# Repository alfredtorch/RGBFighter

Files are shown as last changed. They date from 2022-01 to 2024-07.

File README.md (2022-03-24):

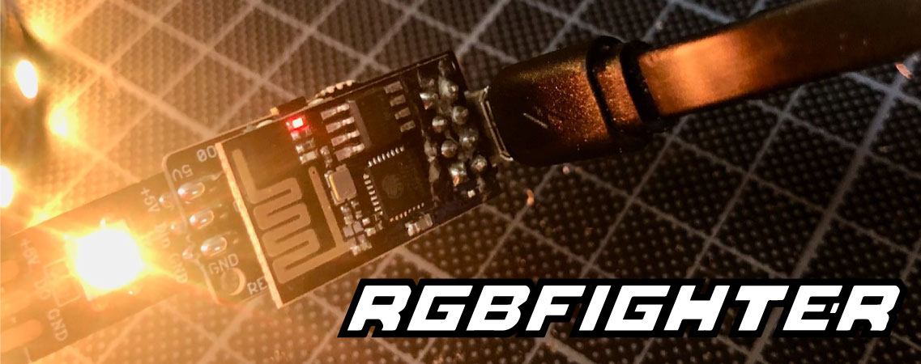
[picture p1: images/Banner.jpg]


🚥 Micro ESP-01 board for addressable pixel control 🚥 ... suits to every place and mostly to any needs!
Only a power bank and a smartphone are needed and you're good to go with your mobile setup.

* Small : +- 14x32mm & Lightweight : +- 4gr
* ESP8266 based (Support for Arduino)
* Designed for common LED Strips like WS2812 with level shifting
* Connection over 2,54 mm 3 Pin for direct soldering, JST or screw terminal (Version Strip or Panel)
* Power and Progamming over USB (CP2104 nodeMCU design)
* User Input for One Button OR IR Receiver
* [WLED](https://github.com/Aircoookie/WLED "WLED's Github page") compatible
* Inspirations from Adafruit, Sparkfun and many others

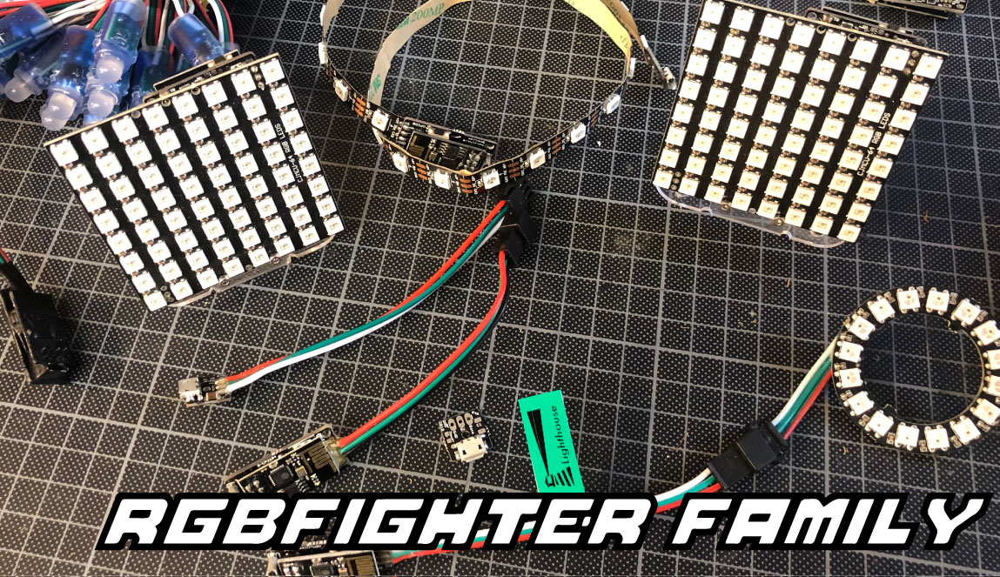
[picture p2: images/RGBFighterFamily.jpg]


# ⚡️PCB 
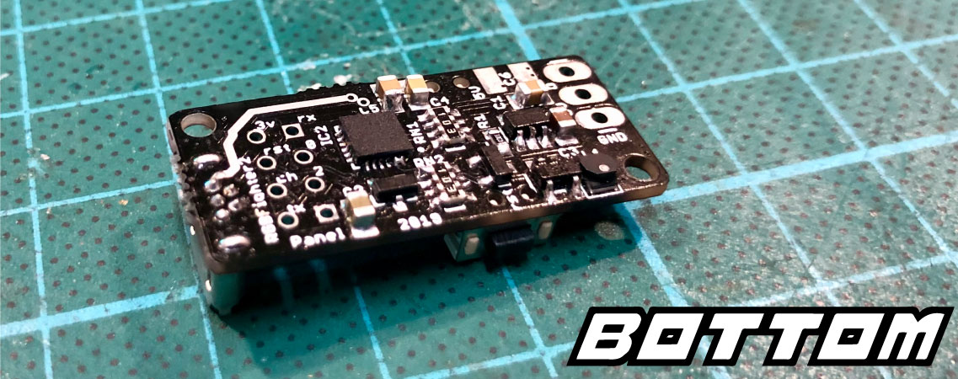
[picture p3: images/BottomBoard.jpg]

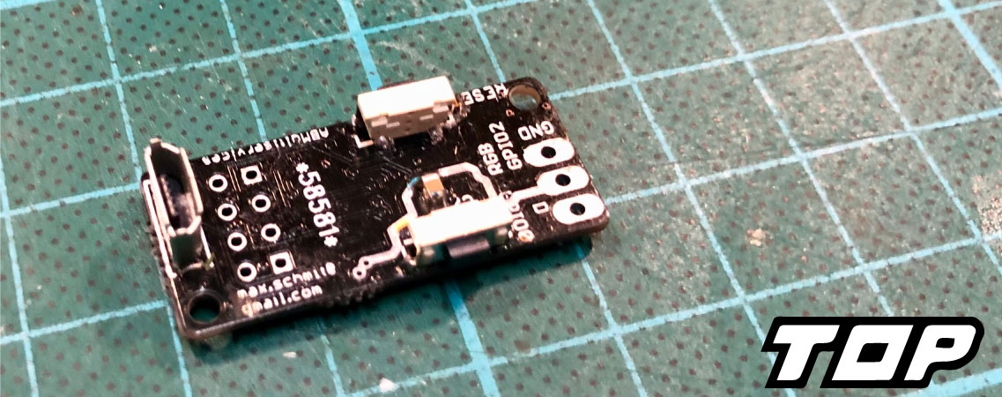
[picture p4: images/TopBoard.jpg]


# 🔦 Hardware

At the moment I have no possibility for a larger production and distribution. Of course, I am ready for any cooperation to industrialize the production. Happy to get any proposition.

## 🗺 Design Files

Designed in Eagle, in a messy way! Sorry! The related files are available under /Hardware.
Name | Description 
--- | ---
ButtonPanel | Panel and Button
ButtonStrip | Strip and Button
IR | Strip and IR Receiver
PowerRail | Power for 8 Strips
PowerDistributorX30 | 5 Ports XT-30 Connector

## 🛠 For DIY'er:
All you need are steady hands for the soldering part, specially the QFN. A reflow or hot plate is suggested.
The thickness of the board should be 1,2mm in order to sold the vertical USB firmly. The parts can be easily ordered from the common suppliers.

## 💰BOM

Part Name | Quantity | Price | Supply Link | Notes 
--- | --- | --- | --- | ---
Board RGBFighter | 1 | 0,02€ | [DirtyCheapPCB](https://dirtypcbs.com/store/pcbs/buy/108056/rgborder10x10january2019-zip) | Panelised Design files of Panel-Strip-USB Versions
ESP-01 MCU | 1x | 2€ | [Amazon](https://amzn.to/3qxXip7) | The brain with Wifi!
CP2104 USB Controller | 1x | 3€ | Mouser, ... | need for progamming : alternative [ESP-01 Flasher Amazon](https://amzn.to/3A2HptF) - [Aliexpress](https://s.click.aliexpress.com/e/_9JcISN)
Micro USB Vertical | 1x | 0,5€ | [Aliexpress](https://s.click.aliexpress.com/e/_AaeVzr)
Resistor Array 603 10k | 2x | 0,2€ | Mouser, ... | Pull-up registors for programming and normal operation
Transistor MMBT2222 | 2x | 0,2€ | Mouser, ... | need for programming, NPN Type
Capacitor 0805 | 3x | 0,2€ | Mouser, ... | Various values : schematics
Inducator 2.2uH | 1x | 0,2€ | Mouser, ... | NRH2412T2R2MNGH
3V3 Step Down Converter | 1x | 1,2€ | Mouser, ... | LM3671
Reistor 300Ohm 0805 | 1x | 0,2€ | Mouser, ... | basic pin protection 
Level Shifter SN74LVC1T45DBV  | 1x | 0,2€ | Mouser, ... | for the right Voltage on the Data bus
Button G71Y | 2x | 0,2€ | [Aliexpress](https://s.click.aliexpress.com/e/_A68Ds9) | MCU & Reset User Input
IR Receiver | 1x | 0,2€ | [Aliexpress](https://s.click.aliexpress.com/e/_A7jhiZ) |IR Control Version

🙏 Please if you need to shop for parts, it would be great that you use the supply links below. As they are affilated, you're supporting me directly to continue to deliver new projects to the community! Thank you ❤️
<p align="center">

</p>

# 🎆 Versions
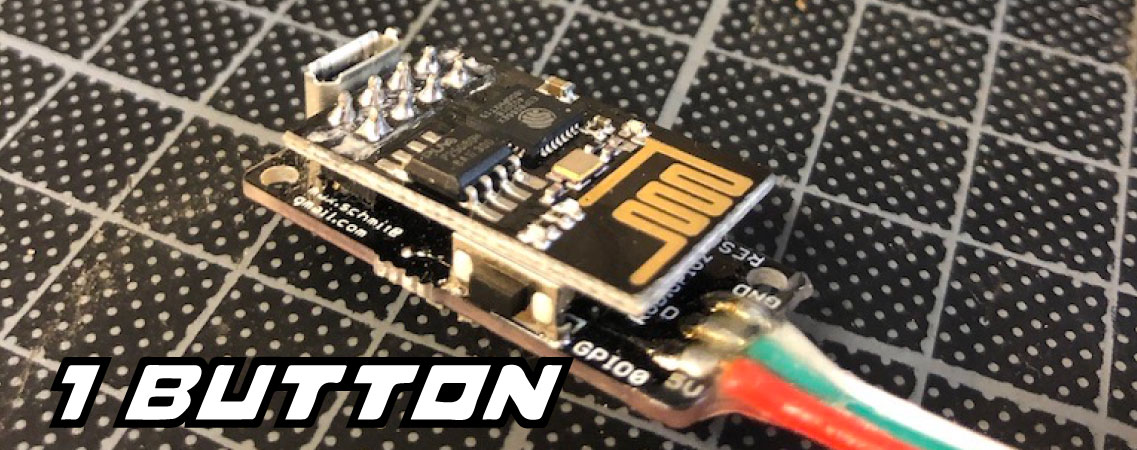
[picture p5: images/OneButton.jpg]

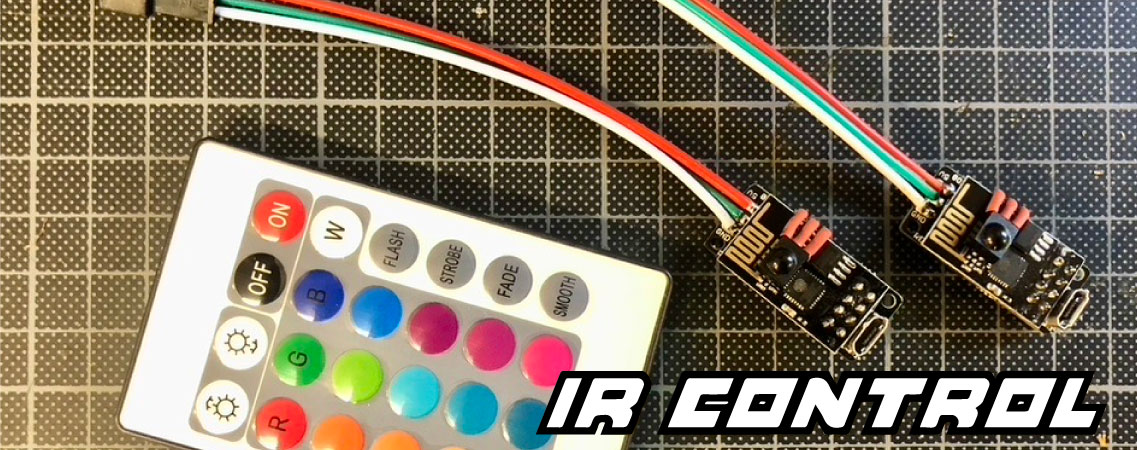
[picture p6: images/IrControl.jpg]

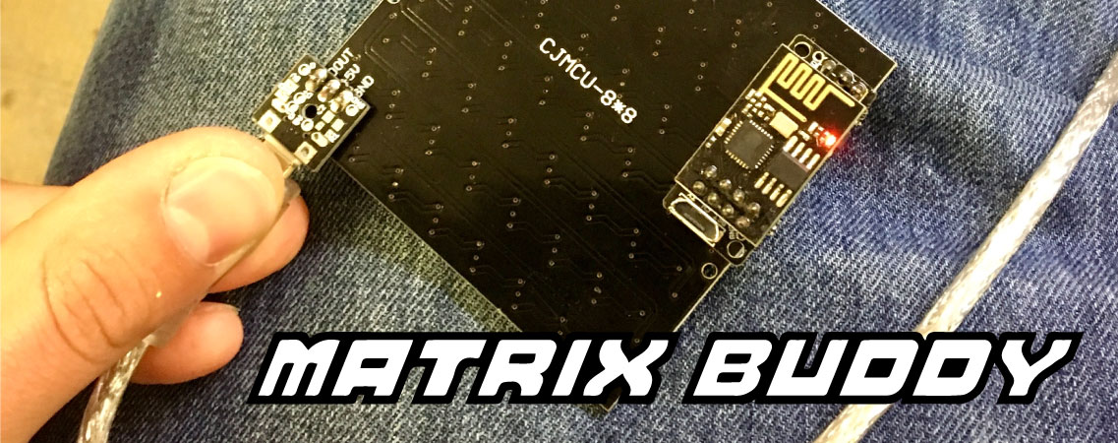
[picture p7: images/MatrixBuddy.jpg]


# 📖 History and Evaluation

It started longtime ago when I wanted an easy way to drive my pixels. First pcb version was sended to fabrication in july 2016. 
Since the project evolved into something more advanced and more mature!

## 🔍 Development Phase
ToDo | Remarks
--- | --- 
Easy Boards | Design boards without programming chip but with easy to solder buttons and voltage converter 
Documentation | Improve the transfer of knowledge
Big production | Looking forward to have some input, help to release it massivly, if wanted.

# 🛒 Accessories

Most of these parts can be laser cutted. The related files are available under Hardware/RGBFighterLaserParts.dxf

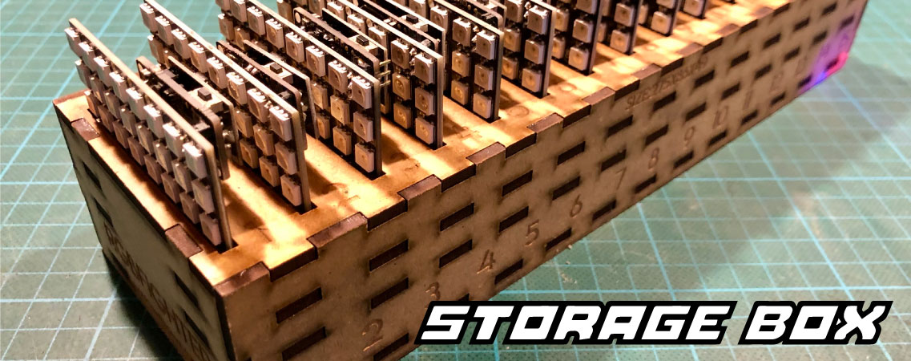
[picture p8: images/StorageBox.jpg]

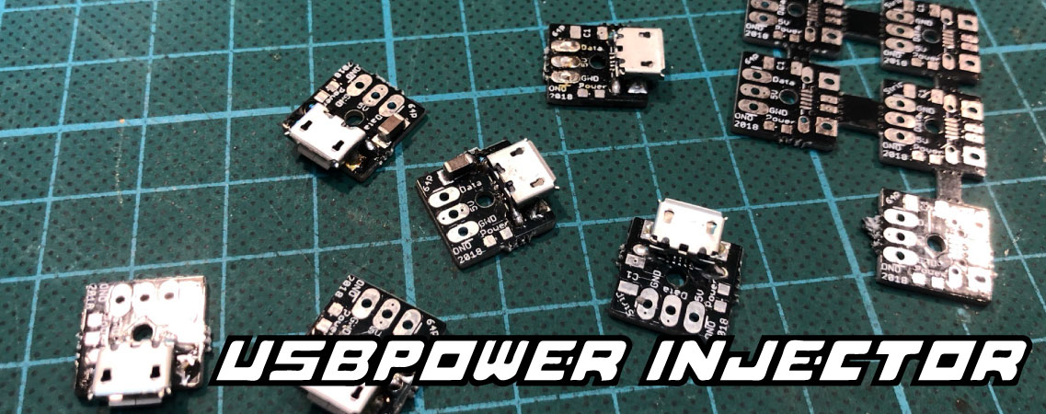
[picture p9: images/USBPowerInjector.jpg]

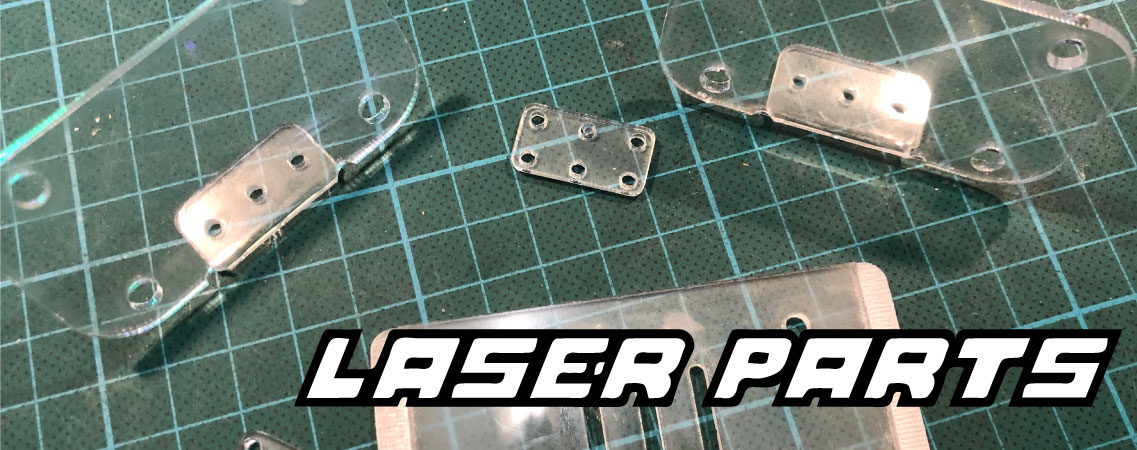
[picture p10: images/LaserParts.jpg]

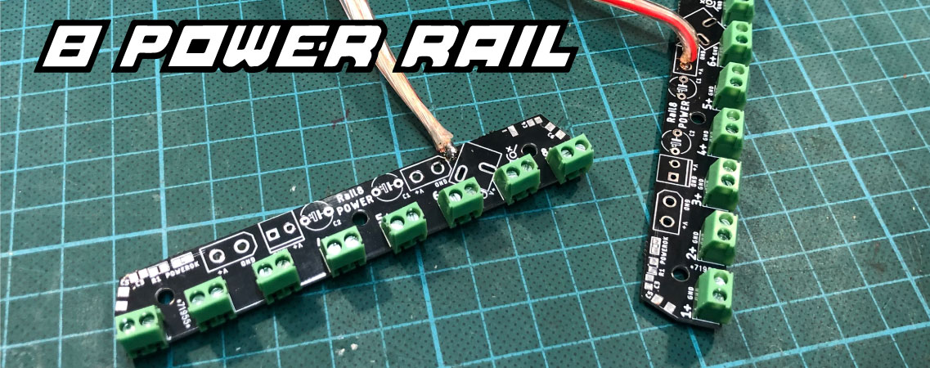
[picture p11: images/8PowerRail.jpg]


# 👶🏼 First Steps & Ideas

⚠️Don't mess with the power - no polarity or whatever protection ⚠️

⚠️Vertical USB is fragile - Handle with care ⚠️

## 🤏🏽 Pinout
Pin | Function
--- | ---
GPIO0 | Button Or InfraRed
GPIO2 | RGB Output | Recomanded Output from WLED

## 💾 Programming
You can directly check the [How-To from WLED](https://kno.wled.ge/basics/install-binary/)

## 🪛 Tutorials
see [Tutorials Page](https://github.com/alfredtorch/RGBFighter/blob/master/Tutorials.md)

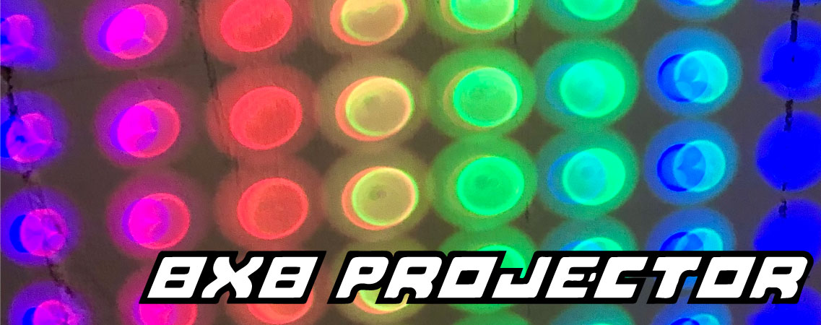
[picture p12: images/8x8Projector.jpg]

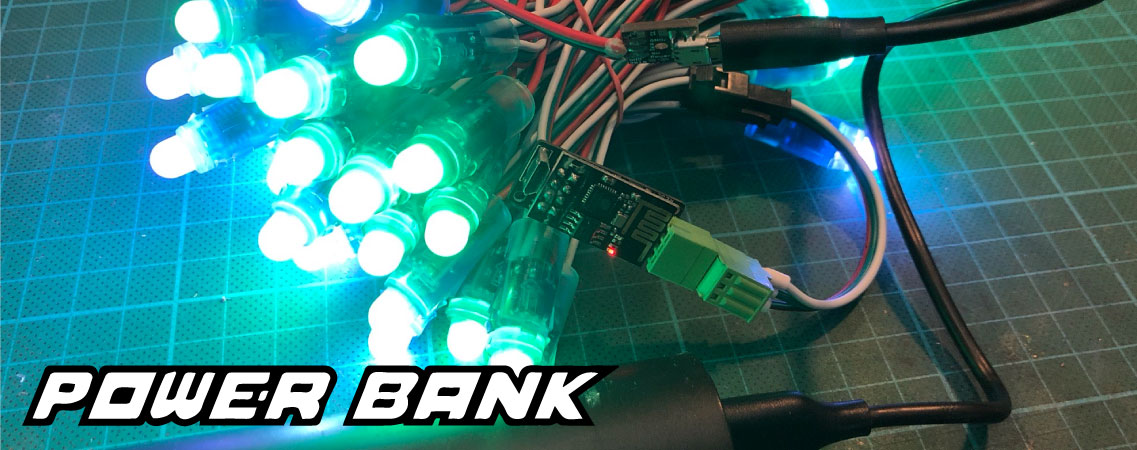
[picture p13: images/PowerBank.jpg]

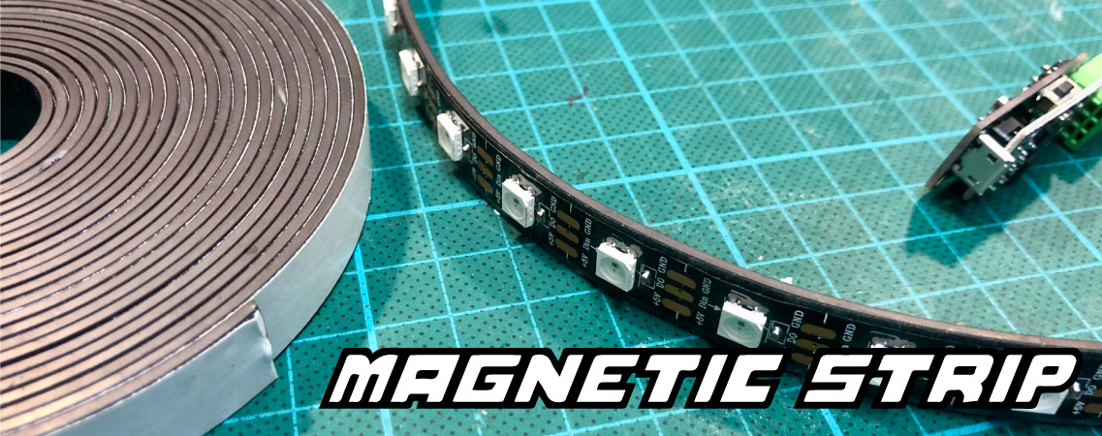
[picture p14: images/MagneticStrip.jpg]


Servo, Electro-Dipped, ...

---

# ⚖️ Licence
The MIT License (MIT)

Copyright (c) 2021 Max Schmit

Permission is hereby granted, free of charge, to any person obtaining a copy of this Hardware and associated documentation files (the "Hardware"), to deal in the Hardware without restriction, including without limitation the rights to use, copy, modify, merge, publish, distribute, sublicense, and/or sell copies of the Hardware, and to permit persons to whom the Hardware is furnished to do so, subject to the following conditions:

The above copyright notice and this permission notice shall be included in all copies or substantial portions of the Software.

THE HARDWARE IS PROVIDED "AS IS", WITHOUT WARRANTY OF ANY KIND, EXPRESS OR IMPLIED, INCLUDING BUT NOT LIMITED TO THE WARRANTIES OF MERCHANTABILITY, FITNESS FOR A PARTICULAR PURPOSE AND NONINFRINGEMENT. IN NO EVENT SHALL THE AUTHORS OR COPYRIGHT HOLDERS BE LIABLE FOR ANY CLAIM, DAMAGES OR OTHER LIABILITY, WHETHER IN AN ACTION OF CONTRACT, TORT OR OTHERWISE, ARISING FROM, OUT OF OR IN CONNECTION WITH THE SOFTWARE OR THE USE OR OTHER DEALINGS IN THE SOFTWARE.

<a href="https://trackgit.com">
trackgit-views
</a>

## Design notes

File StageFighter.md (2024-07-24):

# First-Use
1) Connect your leds to your setup
RGBFighter is intented to use with 12V LED Pixel Strips featuring one data pin (no clock) and two (Positive-Negative).
There are two option to connect the board to the strips.
- Screw Terminal : Use a 2mm screwdriver to secure the 3 wires or Cable Guard in the following order (from right to left): + / Data / -
- Preconfected Cable Connector
Take care about polarity. You can use a DMM to double check voltage and continuity.

2) Connect Your Power Supply
Depending on the number of pixels, select a power supply with sufficient capacity. Use the WLED power calculator: https://wled-calculator.github.io
Example: A setup with four 5-meter-long LED strips at 30px/m draws approximately 8 amps at maximum brightness, exceeding device specifications.
Options for power supply connection:
- USB-C Supply or Power Bank
- ACDC Power Supply with a barrel jack (positive pin inside, 2.1 mm)
- Screw Terminal Adaptor to fix the cable of your choice
- Solder your own XT30 Connector (female). Silicon cables are easier to solder as they won’t melt as easily.
  
3) You’re Ready to Go
Follow the standard routine and tutorials from the WLED community. Happy RGBFighting!
Double-check the ratings of your power supply, especially when using USB-C PD to deliver more than 5V. Check the label rating on your power supply to ensure it can deliver the requested voltage.

# Programming & Compile Settings
## Integrate RGBFighter Definitions in your PlatformIO
1) Visit https://kno.wled.ge/advanced/compiling-wled/ and follow the steps to create your own binary.
2) Once done, rename your platformio.ini to platformio_BCK.ini in your WLED folder.
3) Download CompileSettings/Platformio_RGBFighter.ini and paste it into your WLED folder.
4) Recompile from this repository and open in your IDE Environment (PlatformIO compatible).
5) Follow the normal OTA procedure for upload.

## Physical progamming
1) Disassemble your StageFighter and remove the front plate and all wires attached to it.
2) Remove the shield with the level shifter and place the Flash Device.


Flash device is not yet available on Tindie.

# Power Input
## Voltage Selection
The XT30 connector allows you to deliver up to 30V to your strips. WS2815 pixels, for example, rely on 12V.
By using a USB-B 2.0 to USB-C cable with a regular USB 2.0 power supply, you'll deliver 5V to your LED strips (backward compatibility).
However, due to the integrated DC-DC Converter, you need to ensure a stable 5.0V power source. Measure this with an inline USB power tester.

## Current Rating
Current 20AWG Silicon Wire - Around 5Amp
## Voltage Divider for Power Monitoring. Ships fixed in the choosen USB-C Trigger.
Vin	| R2 Ohms	| R3 Ohms
--- | --- | ---
20V |	1000	| 170
12V	| 1000	| 300
5V	| 1000	| 1200

# Pinout
Pin | Description | Pin | Description
--- | --- | --- | ---
LED D1 | IO14 | LED D2 | IO15
LED D3 | IO17 | LED D4 | IO13
Voltage | IO35 | Temperature | IO02

# Screenshots
<p align="center">

<br>

<br>

</p>

# Components
- Temperature Sensor : DS18B20 for internal enclosure monitoring
- Level Shifter : 74HCT245DW with 200Ohm resistance on each output
- DCDC Converter : ME3116 (max Voltage 40V)
- USB-C PD Trigger : IP2721 with fixed voltage set (max Voltage 30V)

# Version & Development Roadmap
Design Issues: None reported
Etended Temperature Usage: Success (needs to be documented).
Heavy Duty Testing: Maximum Current Setting & Long-term in production field needs to be completed.


# Disclaimer and Warranty Information

## Use Qualification: 
The RGBFighter is designed for users who are qualified and experienced in electronics. Handling and installation of the device should only be performed by individuals who understand the safety precautions necessary for electronic devices.

## Operating Conditions: 
The RGBFighter is not designed for use in harsh environmental conditions. Do not operate the device outdoors, in wet conditions, or in any situation where it is exposed to moisture or extreme temperatures. The device must be monitored during operation to ensure safety and proper functioning.

## Warranty: 
This product is provided 'as is' without any express or implied warranties. Should you encounter any problems, we strongly encourage you to contact us directly to assess the situation. Note that this support does not cover damages attributable to improper installation, connection to incorrect voltages, abuse, alteration, or misuse. The components are part of a broader assembly that is the responsibility of the user to complete and operate correctly. The creators of the RGBFighter are not liable for any damages or injuries resulting from the use or misuse of this product. Use at your own risk.

## Maintenance:
Regular checks (e.g., broken wires, enclosure damage) are recommended to ensure the product's longevity and optimal performance.

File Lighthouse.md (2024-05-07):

# First-Use
1) Connect your leds to your setup
RGBFighter is intented to use with 12V LED Pixel Strips with one data pin (no clock) and two for Positive-Negative.
There are two option to connect the board to the strips.
- Screw Terminal : with a screw driver (2mm) you can place the 3 wires or Cable Guard (from right to left : + / Data / -)
- Preconfected cable connector
Take care about polarity. You can use a DMM to double check (voltage and continuity).

2) Connect your Power Supply
Depending on your amount of pixels, you need to select the right supply capable enough voltage. https://wled-calculator.github.io
Example:
4 led strip each 5 meter long 30px/m draws for maximum brightness around 8 amp (exceeding device specification). In that case a separate power injection should be investigated. Extra layer of safety: isolated protected led outputs & audio input

- USB-C (Check the label rating on your power supply if it can deliver the requested voltage
- DC Barrel with Pin Positive 2,1 mm
- Screw Terminal Adaptor
- Solder your own XT30 Connector!

3) Wifi or Ethernet

Think to double check : 

# Programming & Compile Settings
## Integrate RGBFighter Definitions in your PlatformIO
1) Go to https://kno.wled.ge/advanced/compiling-wled/ and follow the steps needed to create your own binary.
2) Once done, rename your plaformio.ini to plaformio_BCK.ini in your WLED Folder.
3) Download CompileSettings/Platformio_RGBFighter.ini and paste it in your WLED Folder
4) Recompile for from this repositoryand open in your IDE Environement (Platformio compatible).
OTA for upload

## Physical progamming

1) Dissamble your StageFighter and remove the front plate and all the wires attached to it.
2) Remove the shield with level shifher and place

Flash device not yet available.

# Power Input
## Voltage Selection
The XT30 allows the user to deliver voltage up to 30V to its strips. Often Pixels like the popular WS2815 relys on 12V.
This power can be sourced by 
By choosing and USB-B 2.0 to USB-C Cable with a USB 2.0 Power Supply, you'll deliver 5V to your led strips. 
However due the integrated DCDC Converter you need to at least a stable 5.0V power source. 

## Current Rating
Current 20AWG Silicon Wire - Around 5Amp
## Voltage Divider for Power Monitoring. Ships fixed in the choosen USB-C Trigger.
Vin	| R2 Ohms	| R3 Ohms
--- | --- | ---
20V |	1000	| 170
12V	| 1000	| 300
5V	| 1000	| 1200

# Pinout
Pin | Description | Pin | Description
--- | --- | --- | ---
LED D1 | IO14 | LED D2 | IO15
LED D3 | IO17 | LED D4 | IO13
Voltage | IO35 | Temperature | IO02

# Components
- Temperature Sensor : DS18B20 for internal enclosure monitoring
- Level Shifter : 74HCT245DW with 200Ohm resistance on each output
- DCDC Converter : ME3116 (max Voltage 40V)
- USB-C PD Trigger : IP2721 with fixed voltage set (max Voltage 30V)

# Version & Development Roadmap
Design Issues: Reset Button


# Disclaimer and Warranty Information

## Use Qualification: 
The RGBFighter is designed for users who are qualified and experienced in electronics. Handling and installation of the device should only be performed by individuals who understand the safety precautions necessary for electronic devices.

## Operating Conditions: 
The RGBFighter is not designed for use in harsh environmental conditions. Do not operate the device outdoors, in wet conditions, or in any situation where it is exposed to moisture or extreme temperatures. The device must be monitored during operation to ensure safety and proper functioning.

## Warranty: 
This product is provided 'as is' without any express or implied warranties. The creators of the RGBFighter are not liable for any damages or injuries resulting from the use or misuse of this product. Use at your own risk.

## Maintenance:
Regular checks and maintenance are recommended to ensure the product's longevity and optimal performance.

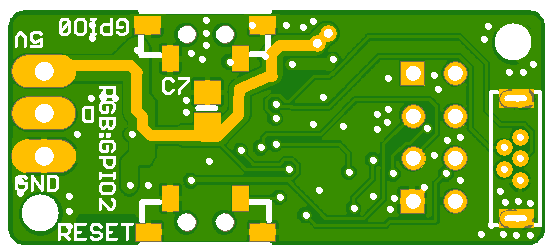
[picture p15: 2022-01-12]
images/WidgetEsp8266RGBv4StripTOPNoID.png

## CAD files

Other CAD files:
Hardware/RGBFighterLaserParts.dxf

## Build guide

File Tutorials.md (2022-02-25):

[⏪ Back to Overview](https://github.com/alfredtorch/RGBFighter/blob/master/README.md)
# 8x8 Projector

## 🛒 Bill-Of-Material

First, grab a 
* Pattern Beam Projector aka 20 Watt RGB Stage Light  [Aliexpress](https://s.click.aliexpress.com/e/_ArDBpP)

* Matrix Panel [Amazon](https://amzn.to/34Iu1PR) [Aliexpress](https://s.click.aliexpress.com/e/_APoWfr).
* M2 screw and washers, prefered Nylon types

## 🛠 Assembly Steps
* Open the projector and remove the led board and the controller. Keep only the genuine power board with the fan.
* Take the old power supply connection (+- 4.5V) and soldered it to directy to the RGBFight board (Pads from unpopulated C5 suits perfectly)
* Prepare the adaptor plate on an laser cutter or CNC. Reduce the the side lips until they into the mounting brackets.
* Screw the matrix panel with attached RGBFighter to the adaptor. Take care about the center alignmentm, adjustable slot holes
* Put everything together and enjoy the show!

## 🎥 Final Setup




# Magnetic Strip

## 🛒 Bill-Of-Material

Grab a 
* [12 mm magnetic strip](https://amzn.to/3IdnUlh)
* [WS2812B or similar strip](https://amzn.to/33G8as0)
and scissors.

## 🛠 Assembly Steps

⚠️ Difficult to have good glue contact between magnetic band and strip. Bad results to glue together with silicon protection ⚠️

## 🎥 Final Setup


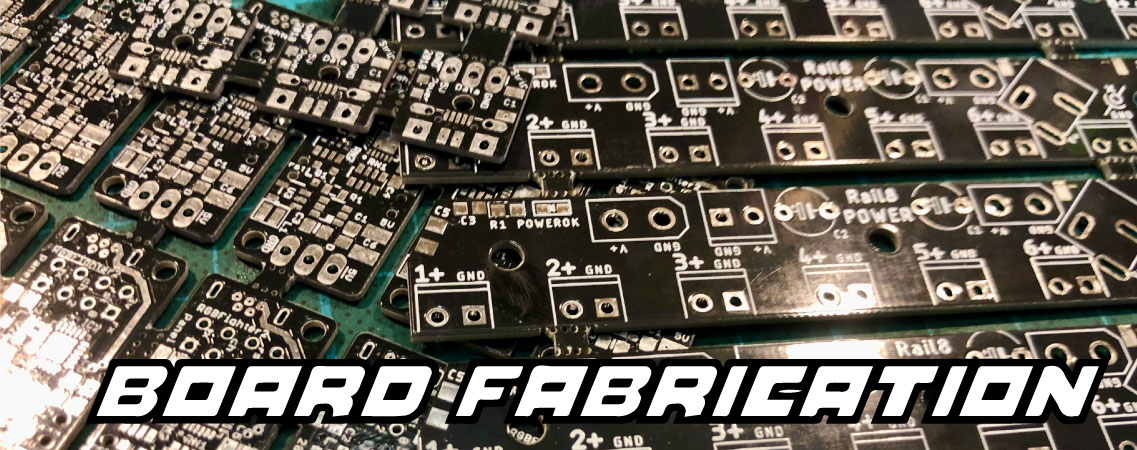
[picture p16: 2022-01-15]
images/BoardFabrication.jpg

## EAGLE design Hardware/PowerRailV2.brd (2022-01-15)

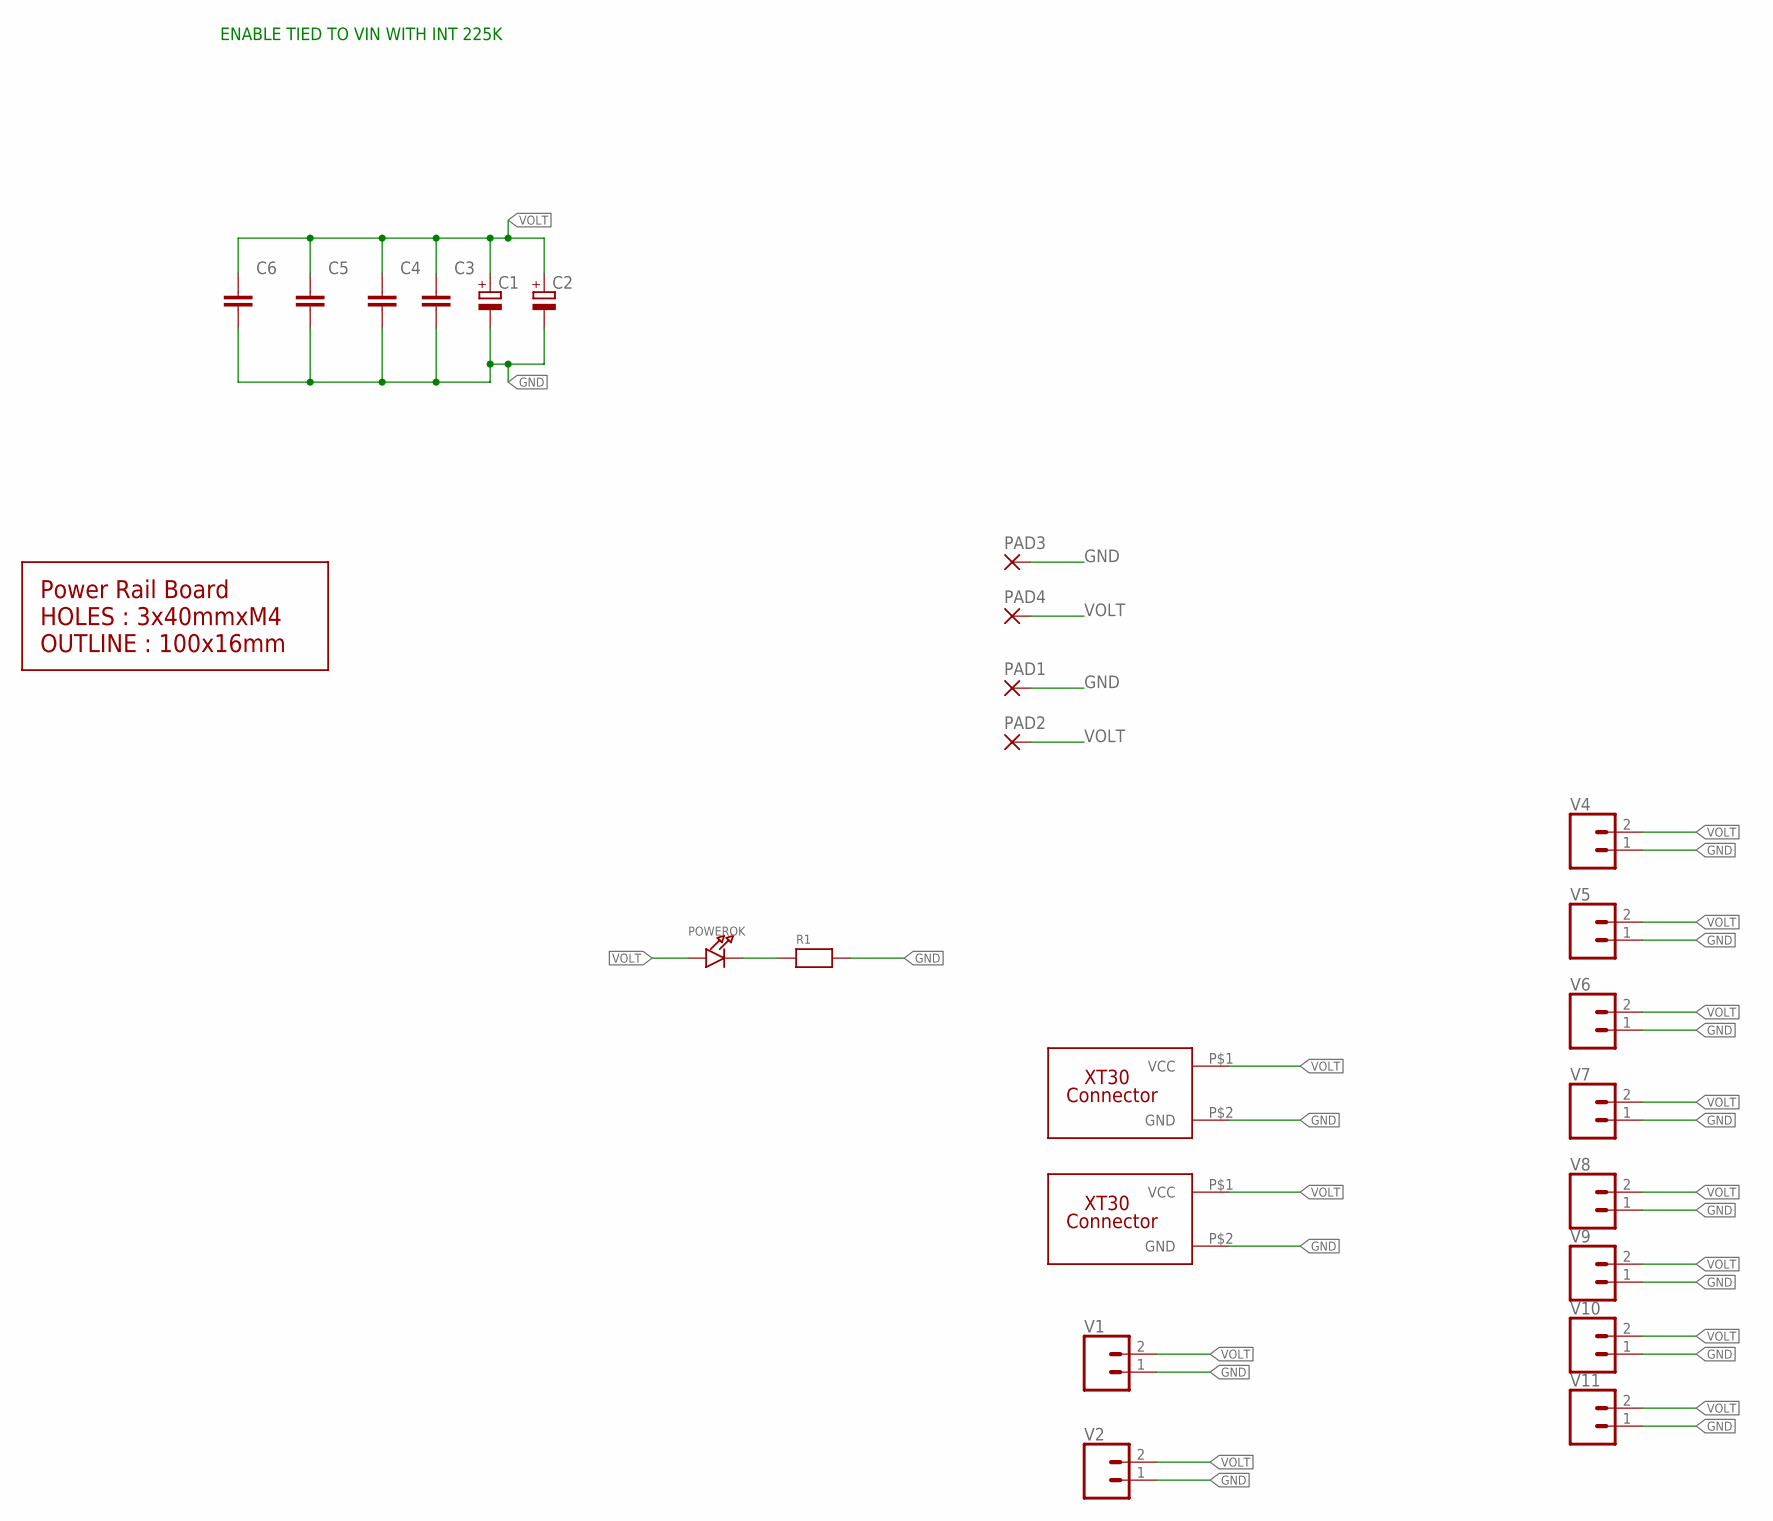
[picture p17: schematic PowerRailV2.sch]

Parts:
C1, C2: CPOL-EUE5-6; E5-6
C3, C4: CAPACITOR_NPOL-0805; C805
C5, C6: CAPACITOR_NPOL-1206; C1206
PAD1, PAD2, PAD3, PAD4: SMD2; SMD1,27-2,54
POWEROK: LED0805; CHIPLED_0805
R1: RESISTOR0805; 0805
U$3: BOARD_POWERRAI_PCB; POWERRAIL_8-LED
U$4, U$6: XT30; XT30-VERT
V1, V2, V4, V5, V6, V7, V8, V9, V10, V11: CONN_023.5MM; SCREWTERMINAL-3.5MM-2

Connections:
GND: C1.-, C2.-, C3.2, C4.2, C5.2, C6.2, PAD1.1, PAD3.1, R1.2, U$4.P$2 (GND), U$6.P$2 (GND), V1.1, V2.1, V4.1, V5.1, V6.1, V7.1, V8.1, V9.1, V10.1, V11.1
unnamed: POWEROK.C, R1.1
VOLT: C1.+, C2.+, C3.1, C4.1, C5.1, C6.1, PAD2.1, PAD4.1, POWEROK.A, U$4.P$1 (VCC), U$6.P$1 (VCC), V1.2, V2.2, V4.2, V5.2, V6.2, V7.2, V8.2, V9.2, V10.2, V11.2

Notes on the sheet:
ENABLE TIED TO VIN WITH INT 225K

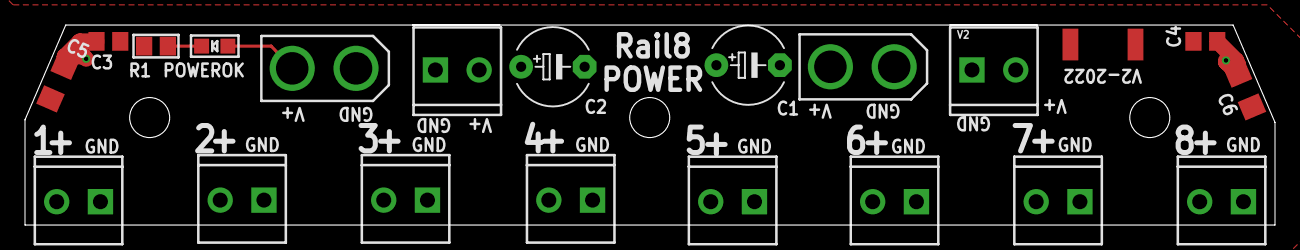
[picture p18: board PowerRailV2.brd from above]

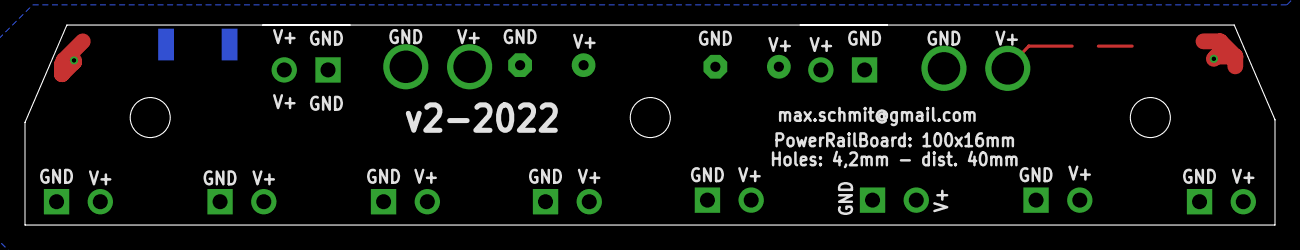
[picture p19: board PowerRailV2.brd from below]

Board: 2 copper layers, 100.0 x 16.0 mm, 25 parts (2 on the bottom side), 3 nets.

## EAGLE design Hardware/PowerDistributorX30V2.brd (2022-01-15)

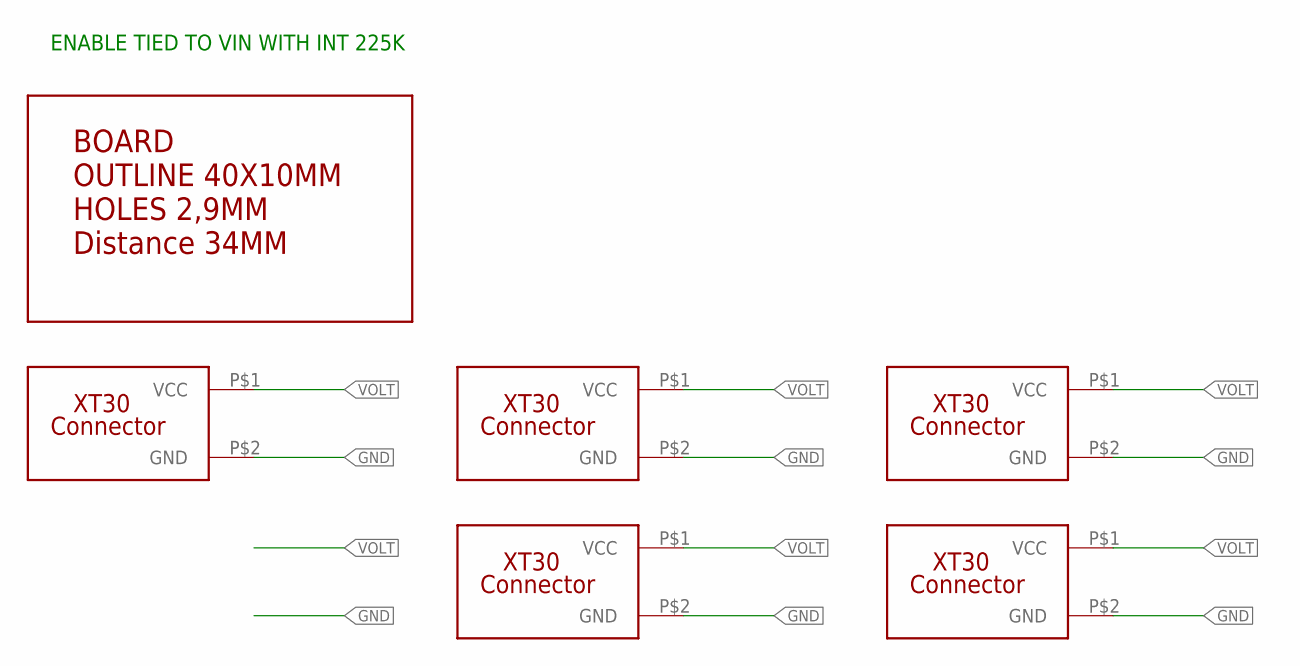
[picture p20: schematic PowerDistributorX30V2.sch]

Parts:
U$1: BOARD40X10; BOARD_40X10-34HOLES
U$2, U$4, U$5, U$6, U$7: XT30; XT30-VERT

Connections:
GND: U$2.P$2 (GND), U$4.P$2 (GND), U$5.P$2 (GND), U$6.P$2 (GND), U$7.P$2 (GND)
VOLT: U$2.P$1 (VCC), U$4.P$1 (VCC), U$5.P$1 (VCC), U$6.P$1 (VCC), U$7.P$1 (VCC)

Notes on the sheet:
ENABLE TIED TO VIN WITH INT 225K

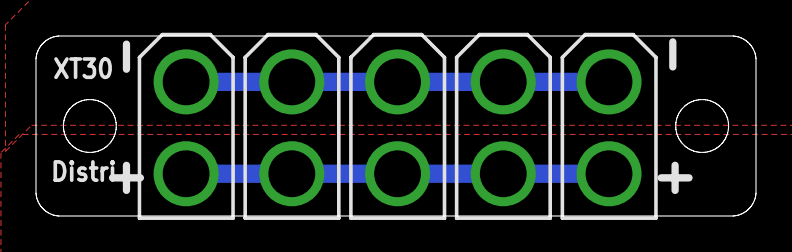
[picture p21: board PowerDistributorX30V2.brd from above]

Board: 2 copper layers, 40.0 x 10.0 mm, 6 parts (0 on the bottom side), 2 nets.

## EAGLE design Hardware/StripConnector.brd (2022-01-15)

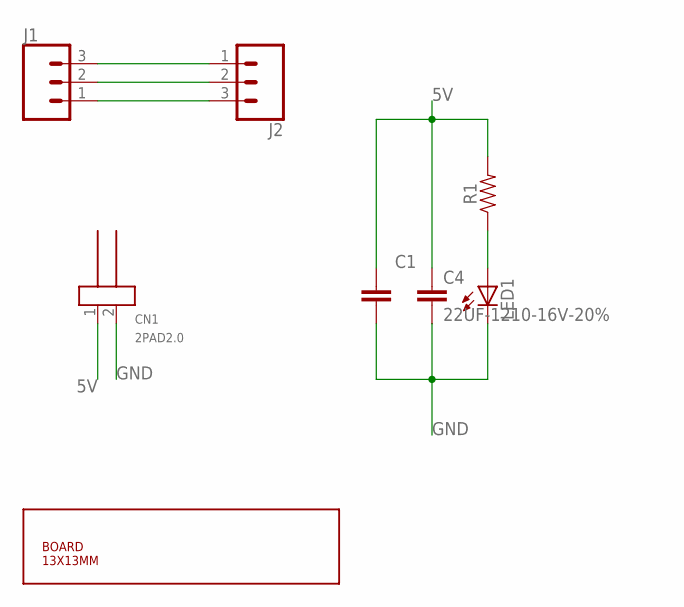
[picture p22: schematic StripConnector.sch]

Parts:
C1: CAPACITOR_NPOL-0805; C805
C4: 22UF-1210-16V-20%; 1210
CN1: 2PAD2.0; 2POLE_P2.0
J1, J2: CONN_03LONGPADS; 1X03_LONGPADS
LED1: LED-0805; LED-805
R1: 0805
U$1: BOARD_13X13MM; 13X13

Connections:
5V: C1.1, C4.1, CN1.1, J1.1, J2.3, R1.2
DATA: J1.2, J2.2
GND: C1.2, C4.2, CN1.2, J1.3, J2.1, LED1.C
unnamed: LED1.A, R1.1

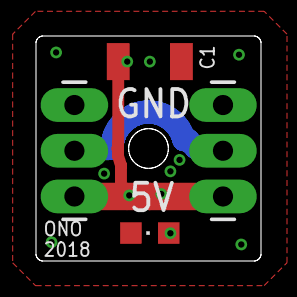
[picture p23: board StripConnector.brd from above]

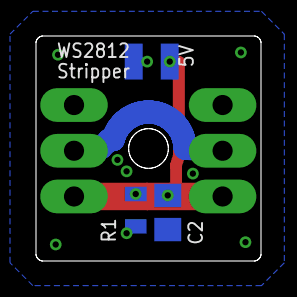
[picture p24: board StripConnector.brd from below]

Board: 2 copper layers, 12.5 x 12.5 mm, 8 parts (3 on the bottom side), 4 nets.

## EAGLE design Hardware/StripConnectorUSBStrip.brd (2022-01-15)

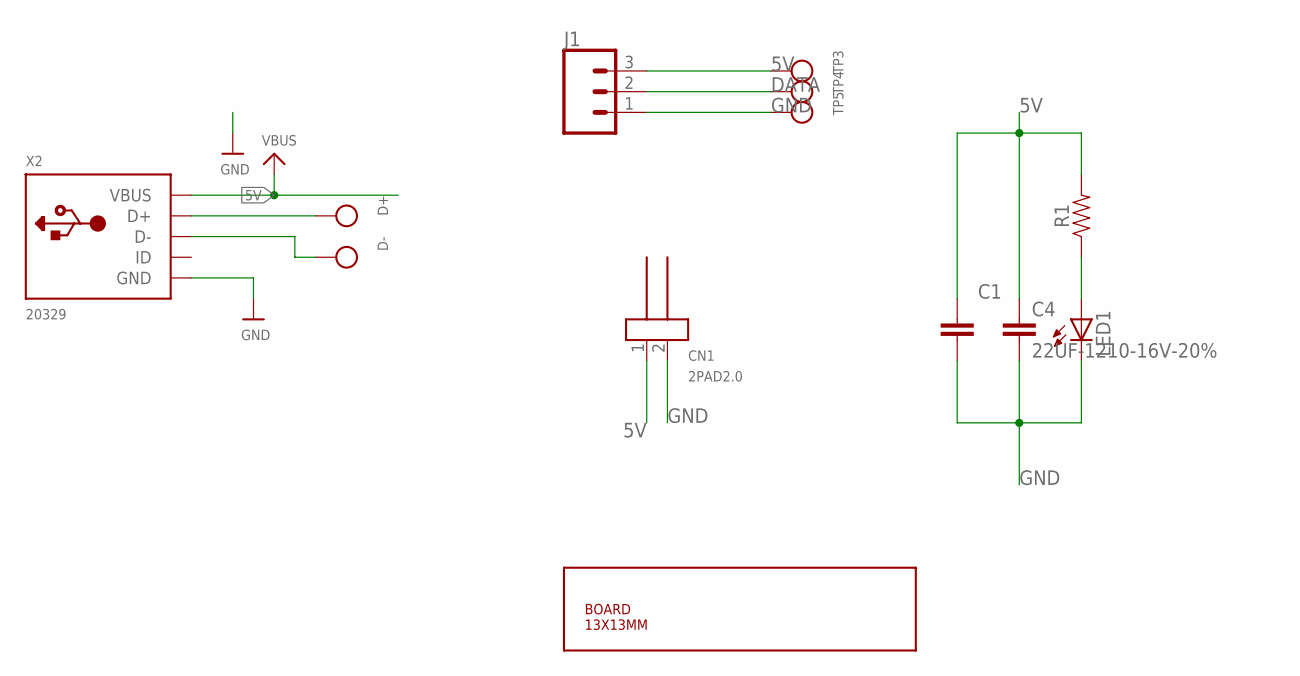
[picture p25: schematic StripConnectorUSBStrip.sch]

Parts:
C1: CAPACITOR_NPOL-0805; C805
C4: 22UF-1210-16V-20%; 1210
CN1: 2PAD2.0; 2POLE_P2.0
D+: TESTPOINTROUND1MM; TESTPOINT_ROUND_1MM
D-: TESTPOINTROUND1MM; TESTPOINT_ROUND_1MM
J1: CONN_03LONGPADS; 1X03_LONGPADS
LED1: LED-0805; LED-805
R1: 0805
TP3, TP4, TP5: TESTPOINTROUND1MM; TESTPOINT_ROUND_1MM
U$1: BOARD_13X13MM; 13X13
X2: 20329; 4UCONN_20329_V2

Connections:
5V: C1.1, C4.1, CN1.1, J1.3, R1.2, TP3.P$1, X2.VBUS
DATA: J1.2, TP4.P$1
GND: C1.2, C4.2, CN1.2, J1.1, LED1.C, TP5.P$1, X2.BASE@1 (GND), X2.BASE@2 (GND), X2.GND, X2.SPRT@1 (GND), X2.SPRT@2 (GND), X2.SPRT@3 (GND), X2.SPRT@4 (GND)
unnamed: D-.P$1, X2.D-
unnamed: LED1.A, R1.1
unnamed: D+.P$1, X2.D+

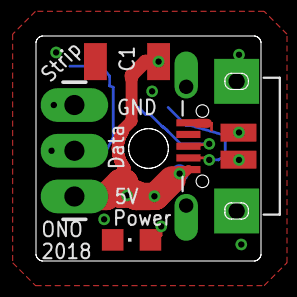
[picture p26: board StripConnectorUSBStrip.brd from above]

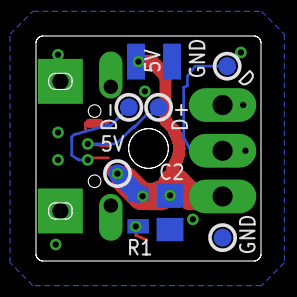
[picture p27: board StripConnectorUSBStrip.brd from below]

Board: 2 copper layers, 12.5 x 12.5 mm, 13 parts (8 on the bottom side), 6 nets.

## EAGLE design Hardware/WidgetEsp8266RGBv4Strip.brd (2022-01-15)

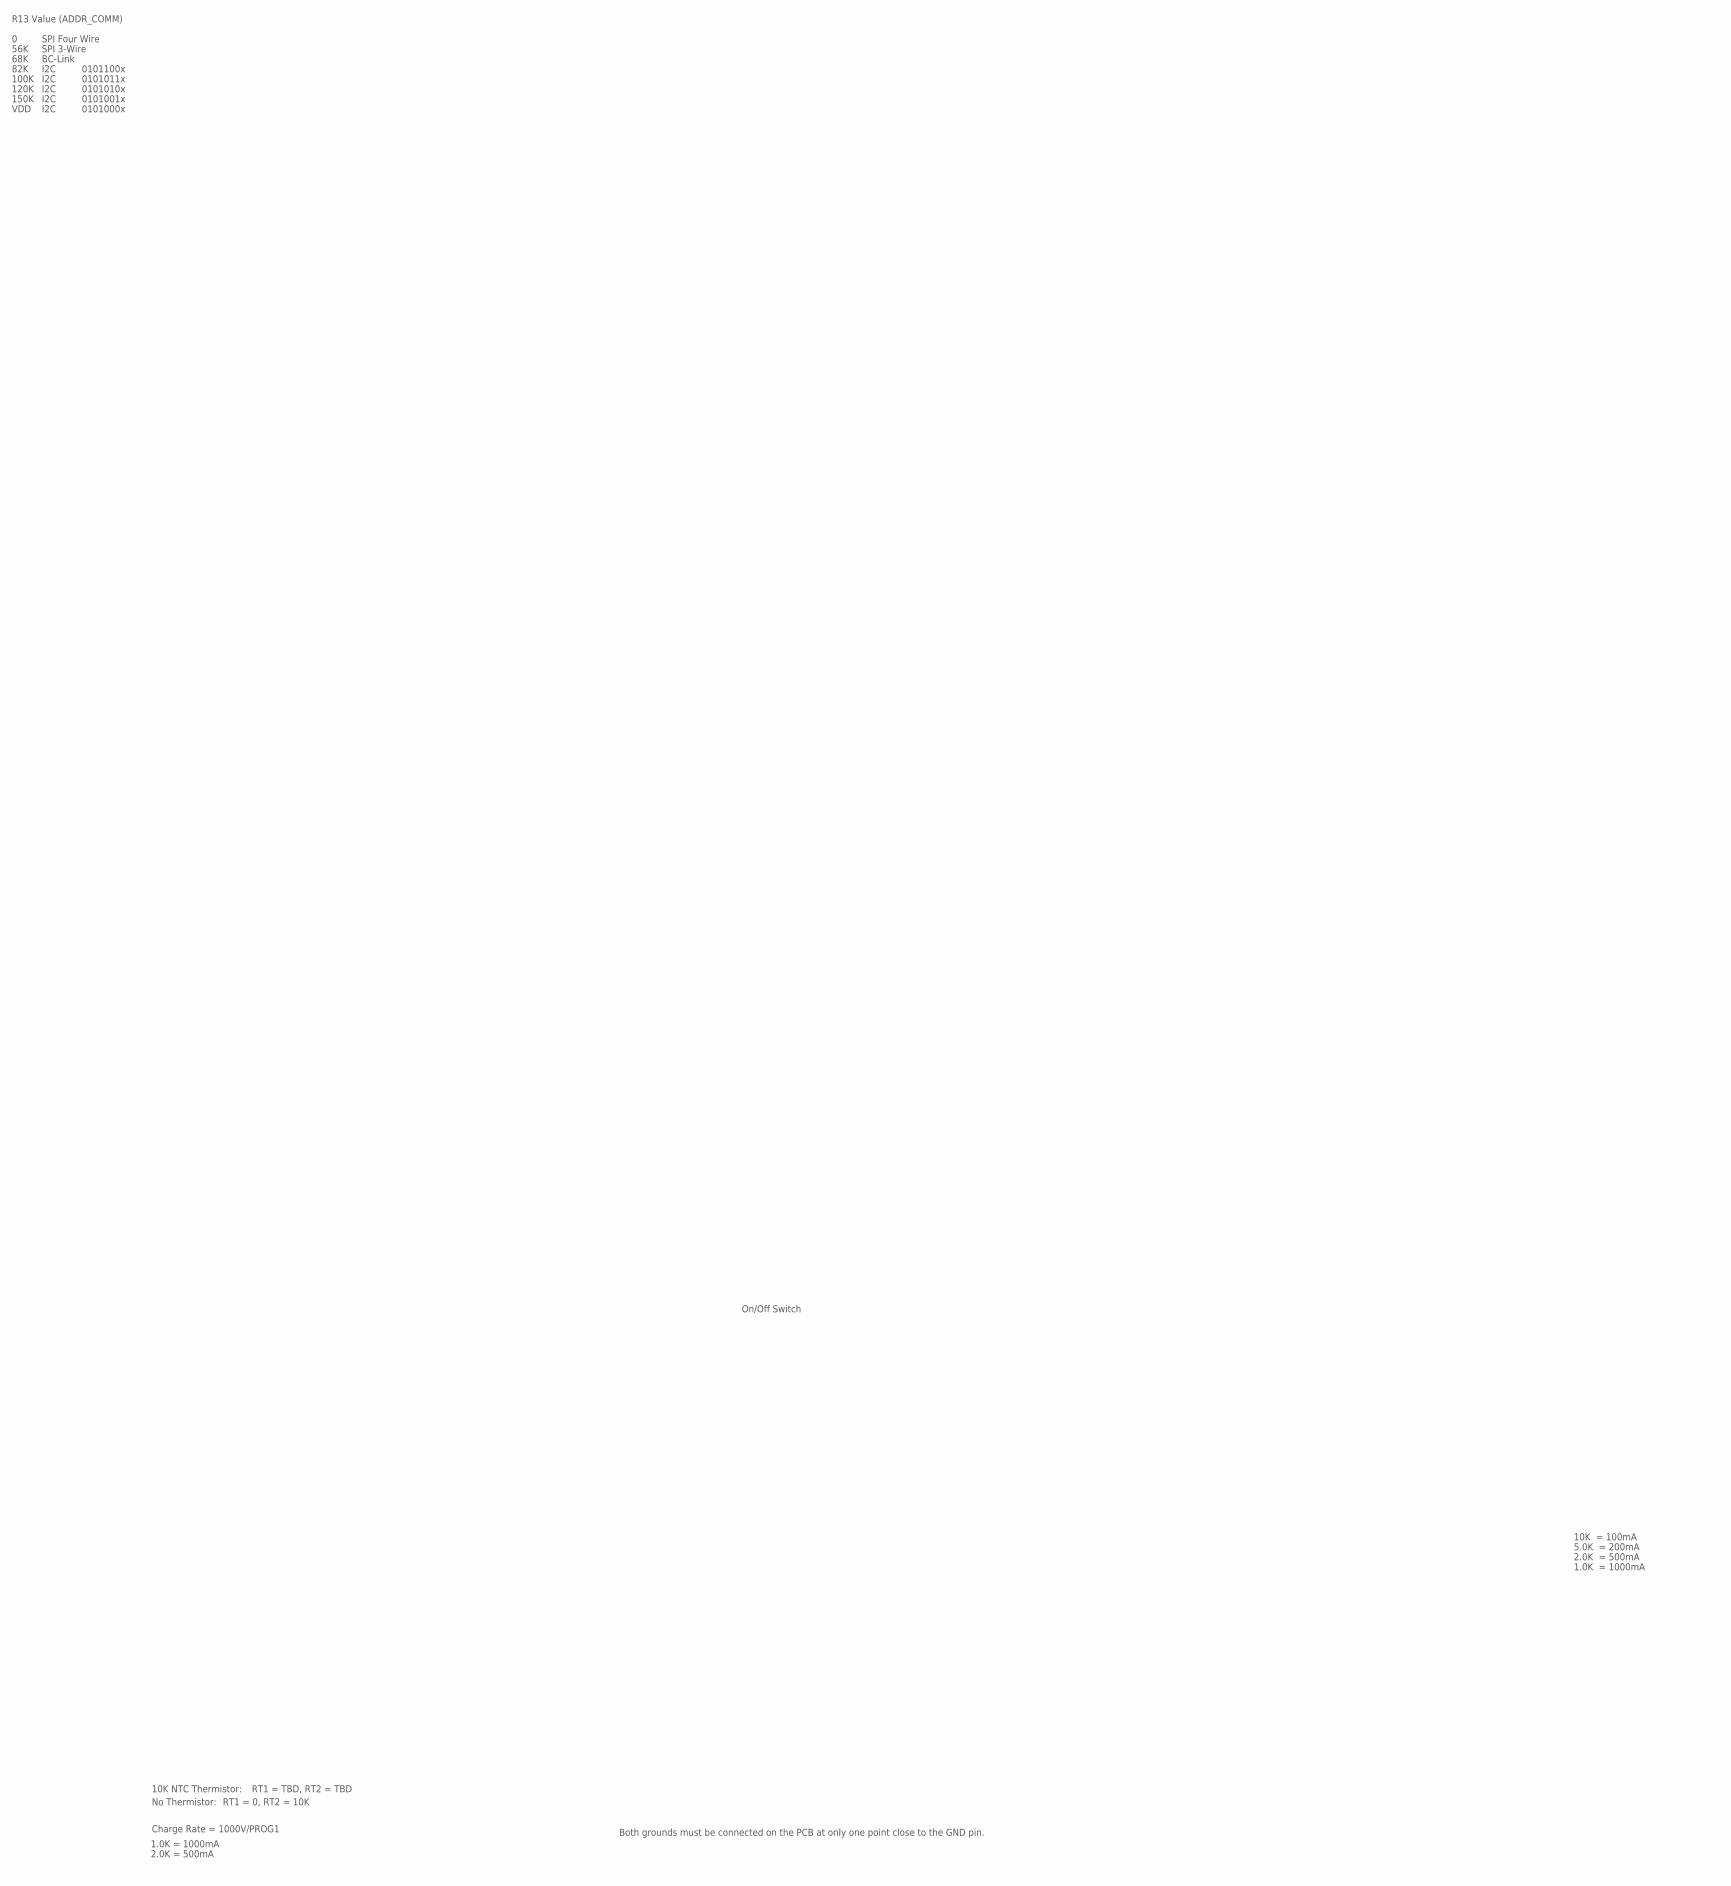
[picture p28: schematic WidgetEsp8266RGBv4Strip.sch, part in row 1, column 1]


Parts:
74LVC1: IC_BUFF_SN74LVC1T45DBV; DBV-R-PDSO-G6
C1, C4: 10uF; 0805-NO
C2, C5, C7: 22uF; 0805-NO
C3: 1uF; 0805-NO
C6: C-USC3225; C3225
ESP: ESP01ONLYDOC; ESP01-NONOSILK
IC2: O -CP2104; QFN24_4MM_SMSC
J13: USB3131-XX-0230-X_REVB; GCT_USB3131-XX-0230-X_REVB
L1: 2.2uH/NRH2412T2R2MNGH; INDUCTOR_TAIYOYUDEN_NRH2412T
Q1, Q2: mmbt2222; SOT23-3
R1: 4; 0805
RGB: CONN_03LONGPADS; 1X03_LONGPADS
RN1, RN2: 10k; RN8P-4R-CRA06S
U3: LM3671MF-3.3/NOPB; SOT23-5
U$4, U$5: 1188
U$7: BOARD14X32; 14X32

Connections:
3V3: 74LVC1.1 (VCCA), C1.2, C2.2, C5.2, ESP.VCC, IC2.5 (VIO), IC2.6 (VDD), IC2.7 (REGIN), L1.2, RN1.4 (1), RN1.6 (2), RN1.7 (2), RN2.1, RN2.2 (1), U3.4 (FB)
5V: 74LVC1.6 (VCCB), C3.2, C4.2, C6.1, C7.2, IC2.8 (VBUS), J13.1 (VBUS), RGB.1, RN2.5 (2), U3.1 (VIN)
DTR: IC2.23 (DTR), Q1.2 (E), RN2.3 (1)
EN: RN2.4 (1), U3.3 (EN)
ESP-CH_PD: ESP.CH_PD, RN2.8 (2)
ESP-USBMINUS3: IC2.4 (D-), J13.2 (D-)
ESP-USBPLUS3: IC2.3 (D+), J13.3 (D+)
GND: 74LVC1.2 (GND), C1.1, C2.1, C3.1, C4.1, C5.1, C6.2, C7.1, ESP.GND, IC2.2 (GND), IC2.THERM (TP), J13.5 (GND), J13.6 (SHIELD), J13.7 (SHIELD), RGB.3, U3.2 (GND), U$4.P$1, U$4.P$2, U$4.P$4 (3), U$5.P$1, U$5.P$2, U$5.P$3 (1)
GPIO0: ESP.GPIO0, Q1.3 (C), RN1.5 (2), U$5.P$4 (3)
GPIO2: 74LVC1.3 (A), ESP.GPIO2, RN1.3 (1)
unnamed: Q2.1 (B), RN2.6 (2)
unnamed: L1.1, U3.5 (SW)
unnamed: Q1.1 (B), RN1.1
unnamed: 74LVC1.5 (DIR), RN1.2 (1)
unnamed: 74LVC1.4 (B), R1.1
NRST: ESP.RST, Q2.3 (C), RN2.7 (2), U$4.P$3 (1)
RTS: IC2.19 (RTS), Q2.2 (E), RN1.8 (2)
RX: ESP.RX (RXD), IC2.21 (TXD)
TO-RGB-TOP: R1.2, RGB.2
TX: ESP.TX (TXD), IC2.20 (RXD)

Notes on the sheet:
R13 Value (ADDR_COMM)
SPI Four Wire
56K
SPI 3-Wire
68K
BC-Link
82K
I2C
0101100x
0101011x
0101010x
0101001x
0101000x
100K
120K
150K
VDD
Both grounds must be connected on the PCB at only one point close to the GND pin.
On/Off Switch
Charge Rate = 1000V/PROG1
1.0K = 1000mA
2.0K = 500mA
No Thermistor:
10K NTC Thermistor:
RT1 = 0, RT2 = 10K
RT1 = TBD, RT2 = TBD
10K = 100mA
5.0K = 200mA
2.0K = 500mA
1.0K = 1000mA
RGB Level Shifter
Buttons
CP2104 Serial USB
ESP01
Power



Board: 2 copper layers, 32.0 x 14.0 mm, 22 parts (6 on the bottom side), 20 nets.

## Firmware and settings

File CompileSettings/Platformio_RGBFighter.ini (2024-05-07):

; PlatformIO Project Configuration File for RGBFighter 
; 7.5.24 - Adding Lighthouse V1 and StageFighter V6
; Integrate or replace this content to your Plaformio.ini in your WLED Folder.
; Please visit documentation: https://docs.platformio.org/page/projectconf.html

[platformio]
# ------------------------------------------------------------------------------
# ENVIRONMENTS
#
# Please uncomment one of the lines below to select your board(s)
# (use `platformio_override.ini` when building for your own board; see `platformio_override.ini.sample` for an example)
# ------------------------------------------------------------------------------

# CI binaries
; default_envs = nodemcuv2, esp8266_2m, esp01_1m_full, esp32dev, esp32_eth # ESP32 variant builds are temporarily excluded from CI due to toolchain issues on the GitHub Actions Linux environment
;default_envs = nodemcuv2, esp8266_2m, esp01_1m_full, nodemcuv2_160, esp8266_2m_160, esp01_1m_full_160, esp32dev, esp32_eth, esp32dev_audioreactive, lolin_s2_mini, esp32c3dev, esp32s3dev_8MB, esp32s3dev_8MB_PSRAM_opi
default_envs = StageFighter
# Release binaries
; default_envs = StageFighter

# Build everything
; default_envs = esp32dev, esp8285_4CH_MagicHome, codm-controller-0_6-rev2, codm-controller-0_6, esp32s2_saola, d1_mini_5CH_Shojo_PCB, d1_mini, sp501e, nodemcuv2, esp32_eth, anavi_miracle_controller, esp07, esp01_1m_full, m5atom, h803wf, d1_mini_ota, heltec_wifi_kit_8, esp8285_H801, d1_mini_debug, wemos_shield_esp32, elekstube_ips

# Single binaries (uncomment your board)
; default_envs = StageFighter

src_dir  = ./wled00
data_dir = ./wled00/data
build_cache_dir = ~/.buildcache
extra_configs =
;  platformio_override.ini

[common]
# ------------------------------------------------------------------------------
# PLATFORM:
#   !! DO NOT confuse platformio's ESP8266 development platform with Arduino core for ESP8266
#
#   arduino core 2.6.3 = platformIO 2.3.2
#   arduino core 2.7.0 = platformIO 2.5.0
# ------------------------------------------------------------------------------
arduino_core_2_6_3 = espressif8266@2.3.3
arduino_core_2_7_4 = espressif8266@2.6.2
arduino_core_3_0_0 = espressif8266@3.0.0
arduino_core_3_2_0 = espressif8266@3.2.0
arduino_core_4_1_0 = espressif8266@4.1.0
arduino_core_3_1_2 = espressif8266@4.2.1

# Development platforms
arduino_core_develop = https://github.com/platformio/platform-espressif8266#develop
arduino_core_git = https://github.com/platformio/platform-espressif8266#feature/stage

# Platform to use for ESP8266
platform_wled_default = ${common.arduino_core_3_1_2}
# We use 2.7.4.7 for all, includes PWM flicker fix and Wstring optimization
#platform_packages = tasmota/framework-arduinoespressif8266 @ 3.20704.7
platform_packages = platformio/toolchain-xtensa @ ~2.100300.220621 #2.40802.200502
                    platformio/tool-esptool #@ ~1.413.0
                    platformio/tool-esptoolpy #@ ~1.30000.0

## previous platform for 8266, in case of problems with the new one
## you'll need  makuna/NeoPixelBus@ 2.6.9 for arduino_core_3_2_0, which does not support Ucs890x
;; platform_wled_default = ${common.arduino_core_3_2_0}
;; platform_packages = tasmota/framework-arduinoespressif8266 @ 3.20704.7
;;                    platformio/toolchain-xtensa @ ~2.40802.200502
;;                    platformio/tool-esptool @ ~1.413.0
;;                    platformio/tool-esptoolpy @ ~1.30000.0

# ------------------------------------------------------------------------------
# FLAGS: DEBUG
# esp8266 : see https://docs.platformio.org/en/latest/platforms/espressif8266.html#debug-level
# esp32   : see https://docs.platformio.org/en/latest/platforms/espressif32.html#debug-level
# ------------------------------------------------------------------------------
debug_flags = -D DEBUG=1 -D WLED_DEBUG
  -DDEBUG_ESP_WIFI -DDEBUG_ESP_HTTP_CLIENT -DDEBUG_ESP_HTTP_UPDATE -DDEBUG_ESP_HTTP_SERVER -DDEBUG_ESP_UPDATER -DDEBUG_ESP_OTA -DDEBUG_TLS_MEM ;; for esp8266
  # if needed (for memleaks etc) also add; -DDEBUG_ESP_OOM -include "umm_malloc/umm_malloc_cfg.h"
  # -DDEBUG_ESP_CORE is not working right now
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

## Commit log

2024-05-07 Update and rename StageFighter.md to Lighthouse.md
2024-05-07 Create StageFighter

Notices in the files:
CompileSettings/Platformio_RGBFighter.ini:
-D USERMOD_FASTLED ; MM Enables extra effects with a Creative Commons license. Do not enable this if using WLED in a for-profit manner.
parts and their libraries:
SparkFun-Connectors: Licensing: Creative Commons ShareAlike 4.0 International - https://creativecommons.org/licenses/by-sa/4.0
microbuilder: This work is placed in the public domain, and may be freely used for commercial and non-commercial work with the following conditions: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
